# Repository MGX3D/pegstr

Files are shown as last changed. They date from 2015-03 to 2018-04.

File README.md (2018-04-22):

# Pegstr - Pegboard Wizard
__Parametric Peg Board Mounts Generator__
*Infinite ways to create pegboard holders and bins for tools or display objects.* 

__Highlights__:

* One or multiple (m•n matrix) objects per holder
* Round, square or rectangular with rounded corners
* Generate various shapes of bins and trays (closed bottom)
* Chose between stronger or economical, straight or tapered, etc
* Can be partially open (to click / snap in objects) and angled up or down

Note: This is designed to work with US-style pegboard (1/4" holes, 1" spaced) but I'm working on updating the design to support other pegboards requested in the comments.

Example objects:

Pegstr (https://youtu.be/gb9It1dF2z4)

Pegstr Bins (http://youtu.be/T17yfQddx3c)

Thingiverse page: http://www.thingiverse.com/thing:537516

Examples of mixed configurations:

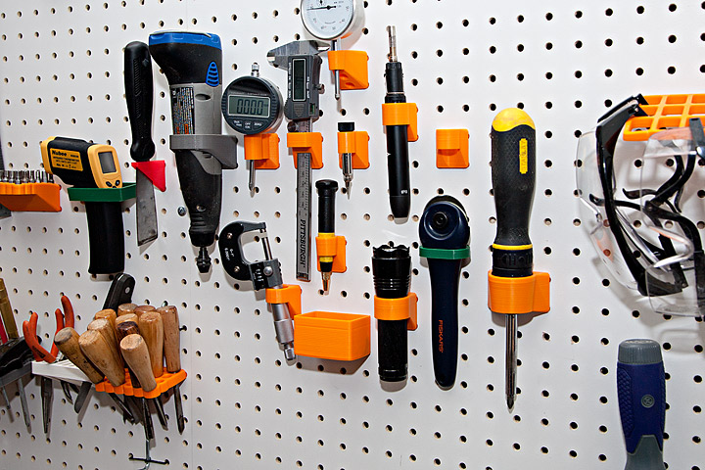
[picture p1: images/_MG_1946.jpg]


Example of MT2 supports:

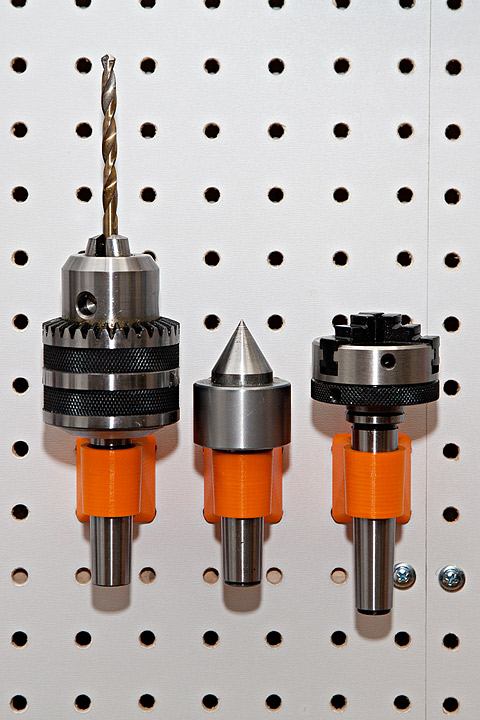
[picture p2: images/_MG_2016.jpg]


Example of hex bits holder:

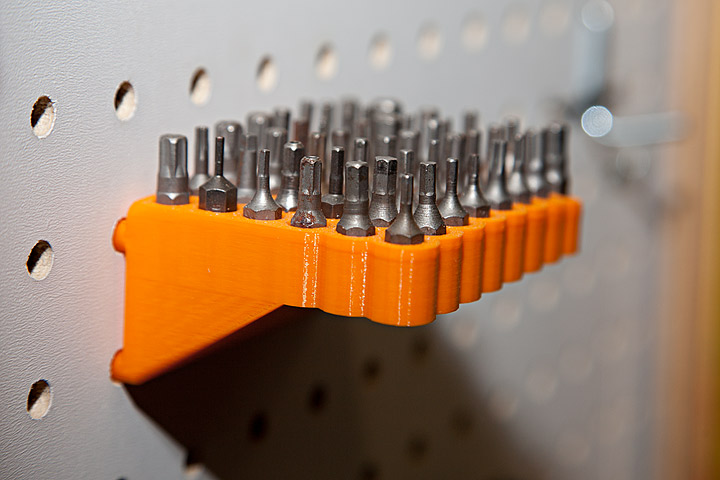
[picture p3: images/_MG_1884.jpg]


Note: this is CC-NC (Creative Commons - Attribution - Non-Commercial), if you intend to use this for commercial purposes please contact me first.

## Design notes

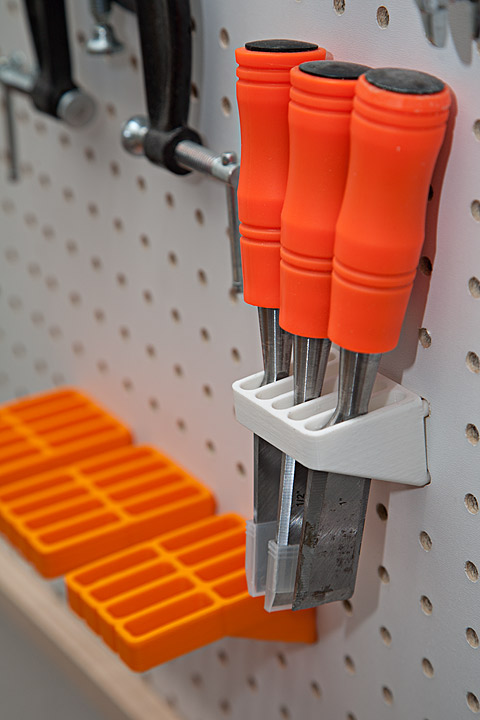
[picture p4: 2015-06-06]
images/_MG_1919.jpg

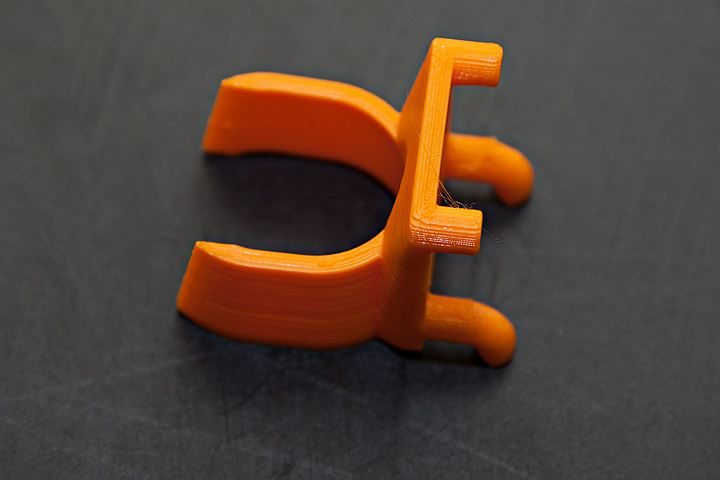
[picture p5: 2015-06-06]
images/_MG_2010.jpg

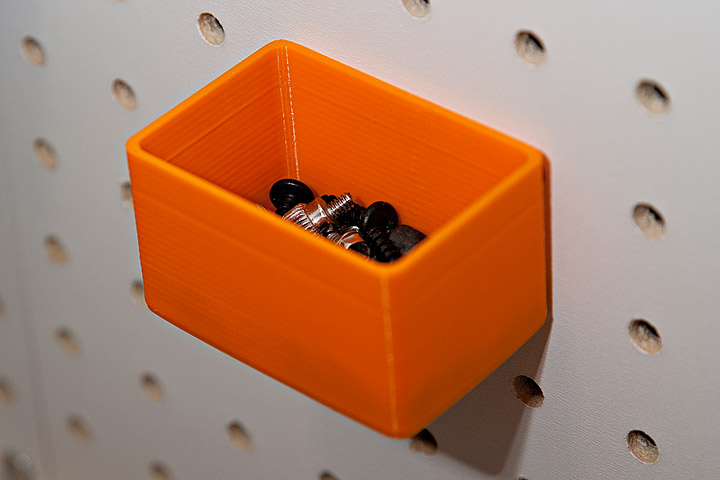
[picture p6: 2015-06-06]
images/_MG_1929.jpg

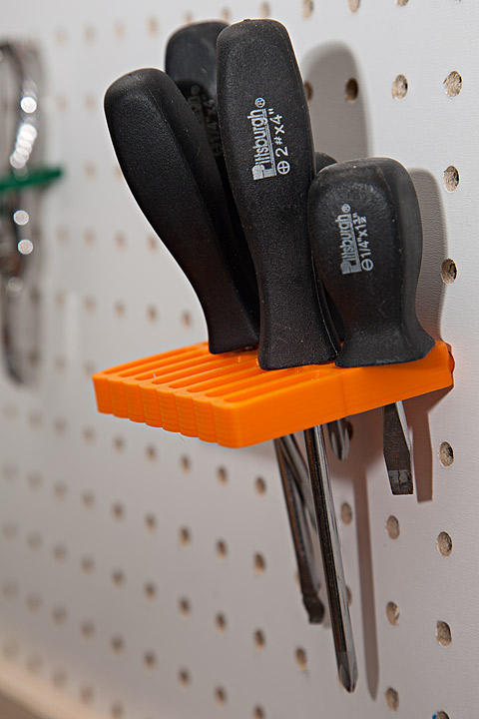
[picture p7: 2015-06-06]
images/_MG_1963.jpg

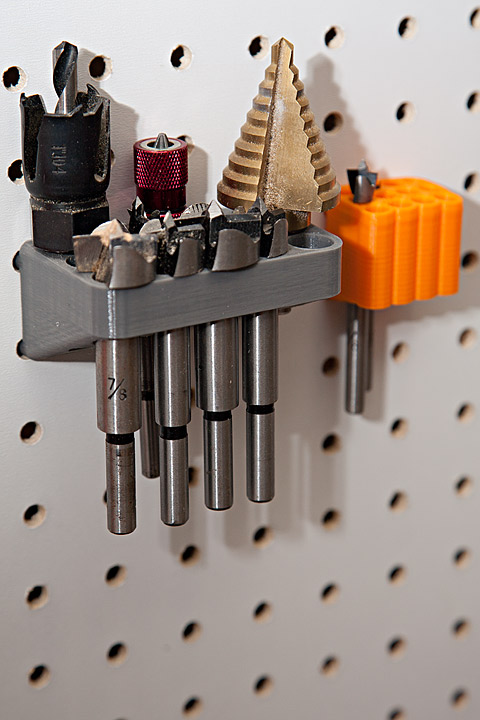
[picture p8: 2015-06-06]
images/_MG_1958.jpg

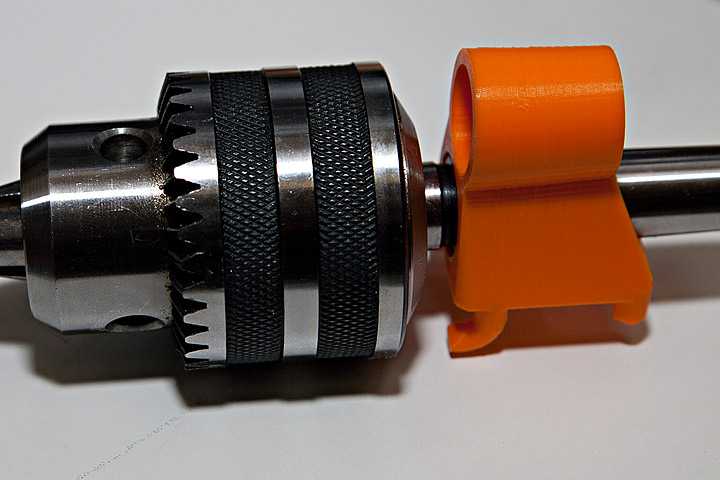
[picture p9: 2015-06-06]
images/_MG_1984.jpg

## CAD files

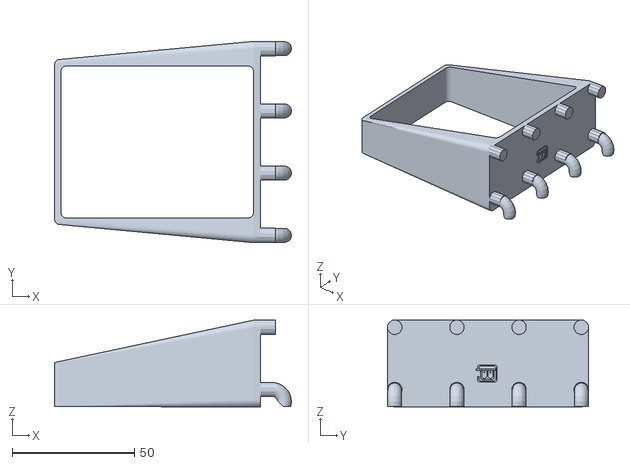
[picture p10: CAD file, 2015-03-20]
Samples/BD Matrix Drill Set/PegBoard_BDMatrix_base.stl
96.8 x 82.2 x 35.4

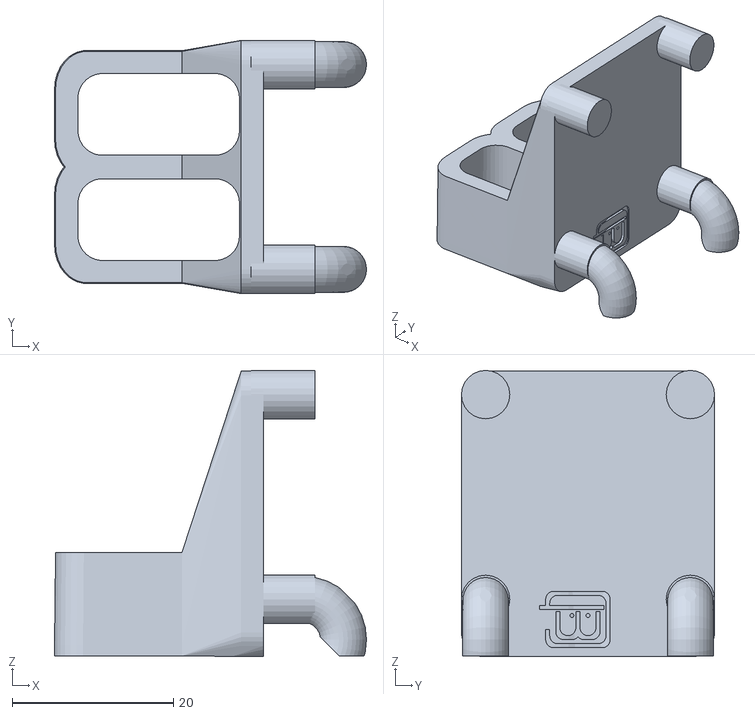
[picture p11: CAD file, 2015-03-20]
Samples/PegBoard_2by1_10x20.stl
38.7 x 31.4 x 35.5

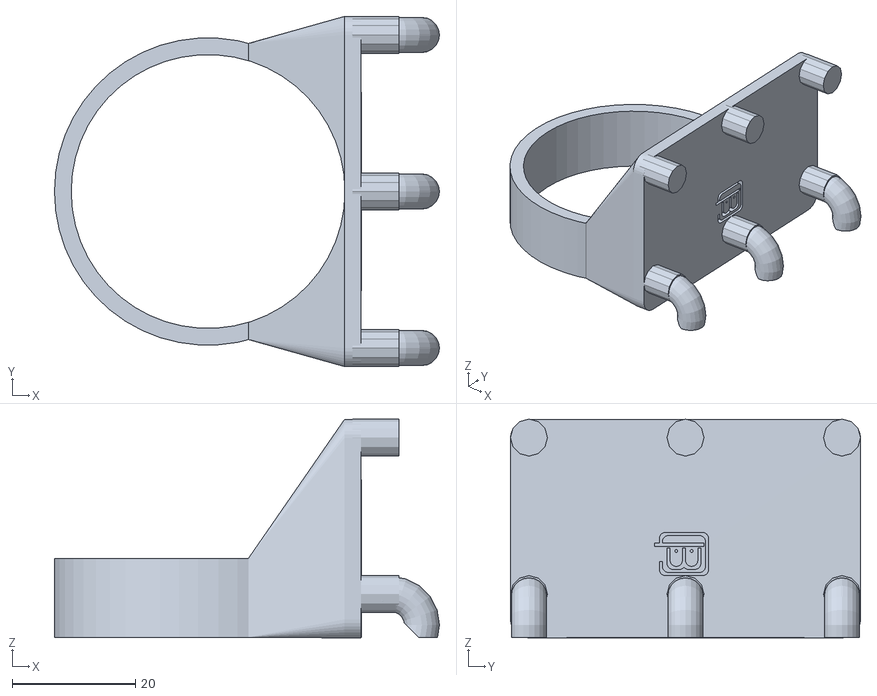
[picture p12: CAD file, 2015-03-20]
Samples/BD Matrix Drill Set/PegBoard_44mm.stl
62.5 x 56.8 x 35.5

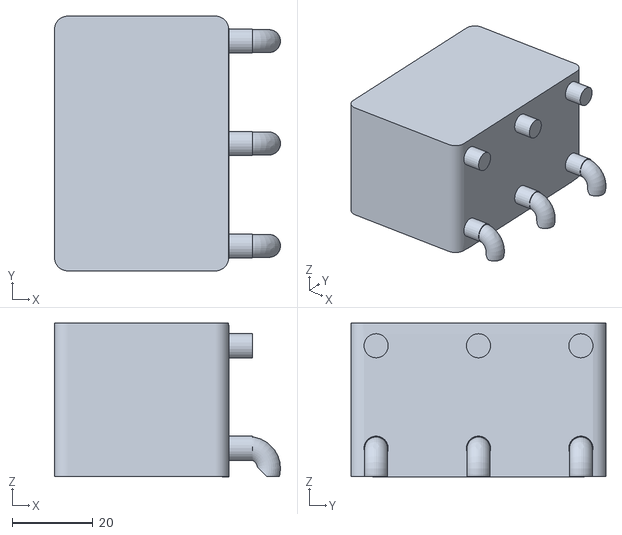
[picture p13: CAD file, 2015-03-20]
Samples/PegBoard_box_60x40.stl
56.1 x 63.2 x 38.1

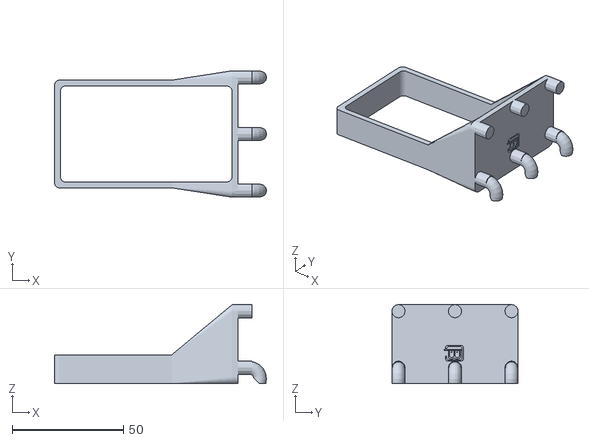
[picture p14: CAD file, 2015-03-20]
Samples/BD Matrix Drill Set/PegBoard_LBX20_battery.stl
95.3 x 56.8 x 35.5

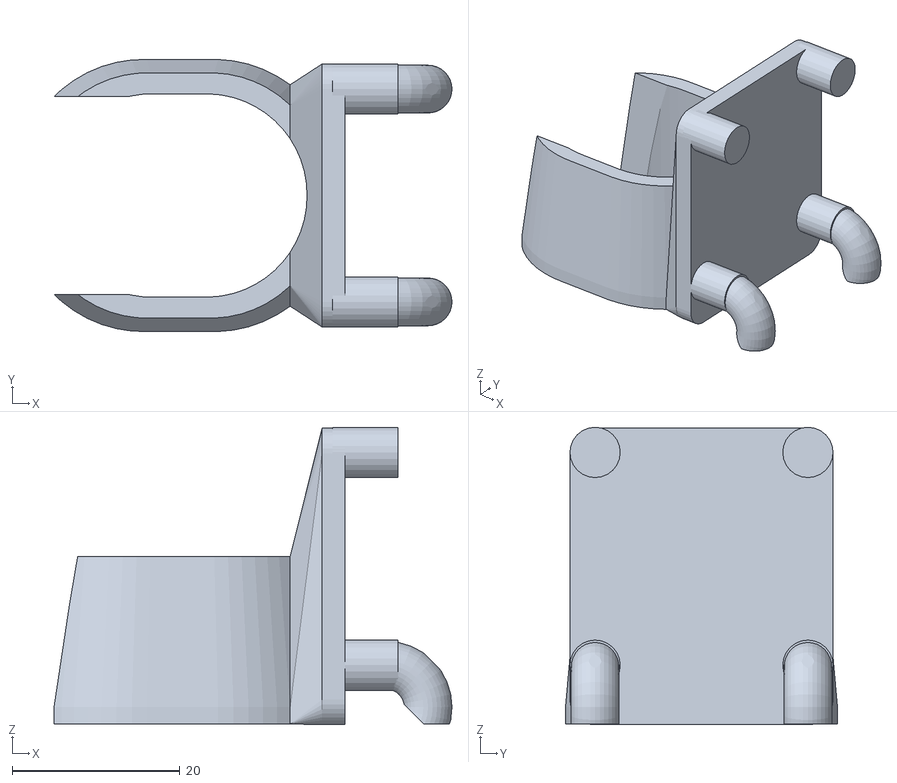
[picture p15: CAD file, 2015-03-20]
Samples/PegBoard_windscreen_tool.stl
47.5 x 32.5 x 35.5

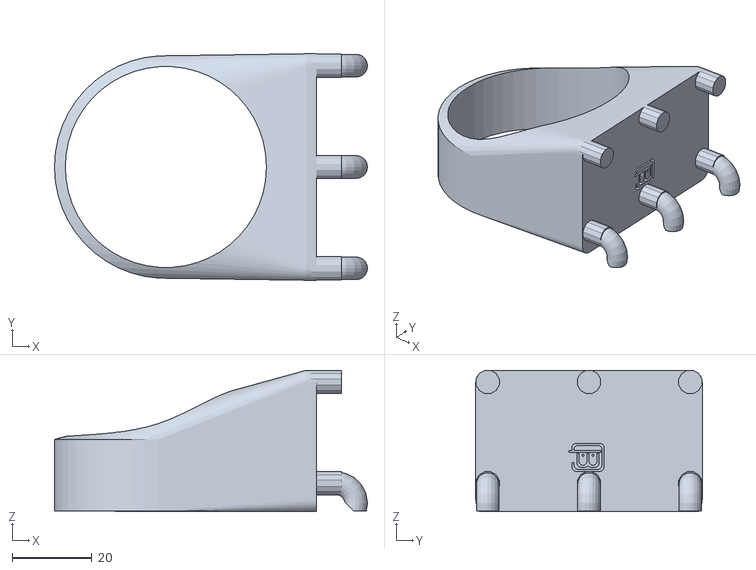
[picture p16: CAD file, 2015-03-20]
Samples/BD Matrix Drill Set/PegBoard_BDMatrix_tip.stl
78.5 x 56.8 x 35.4

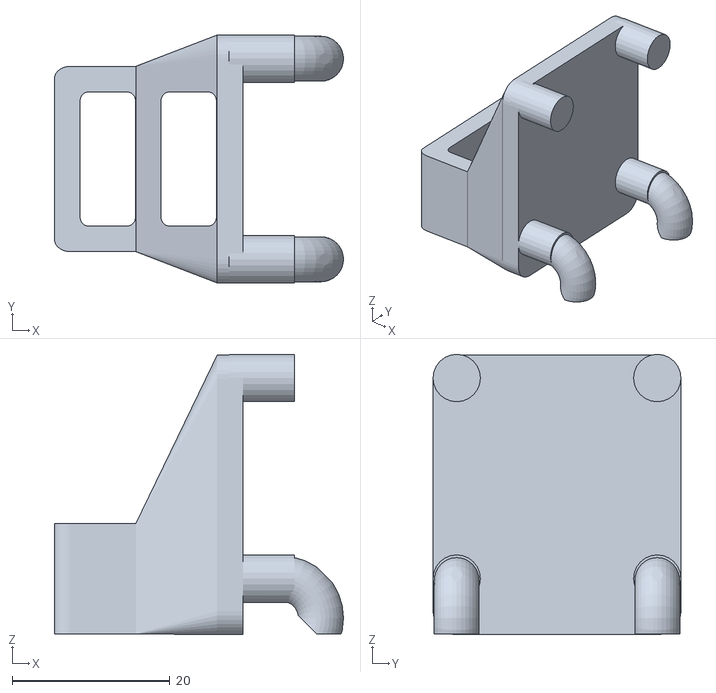
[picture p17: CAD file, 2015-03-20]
Samples/PegBoard_caliper.stl
36.6 x 31.4 x 35.5

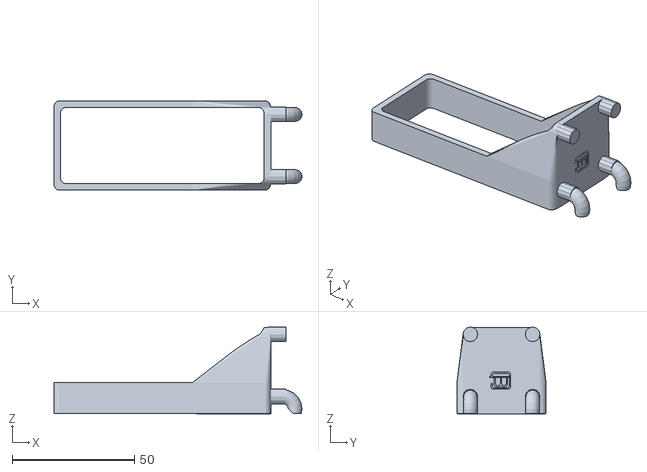
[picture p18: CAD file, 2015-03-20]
Samples/BD Matrix Drill Set/PegBoard_LBX20_charger.stl
101.3 x 36.4 x 35.5

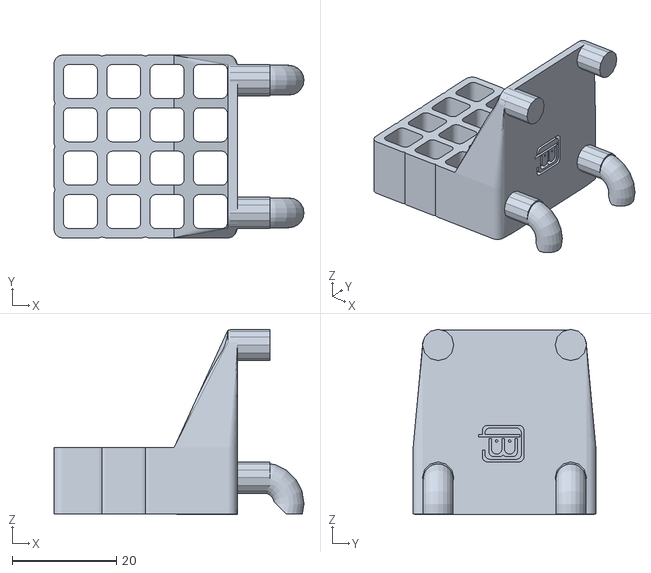
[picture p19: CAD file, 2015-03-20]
Samples/PegBoard_4by4_6.5x6.5.stl
47.9 x 35.0 x 35.5

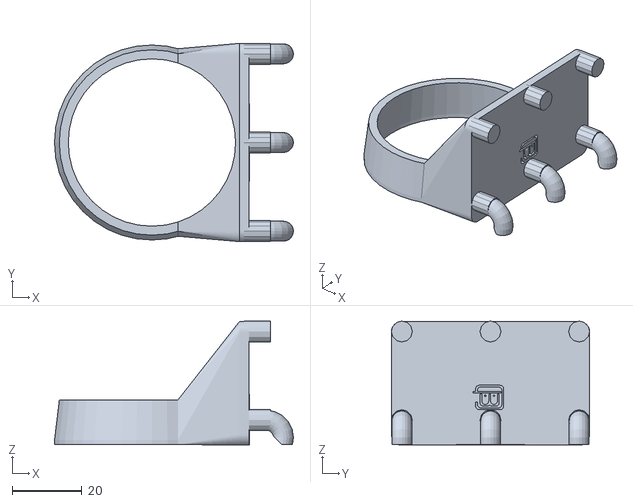
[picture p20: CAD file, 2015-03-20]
Samples/BD Matrix Drill Set/PegBoard_50mm_tapered.stl
68.5 x 56.8 x 35.5

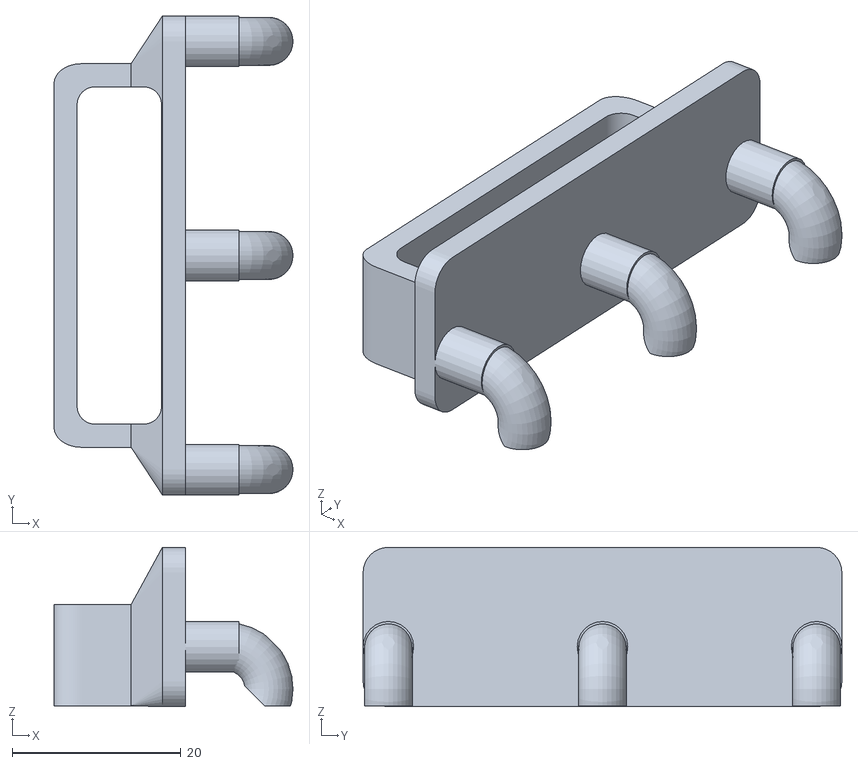
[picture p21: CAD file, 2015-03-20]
Samples/PegBoard_40x10_small.stl
28.4 x 56.8 x 18.9

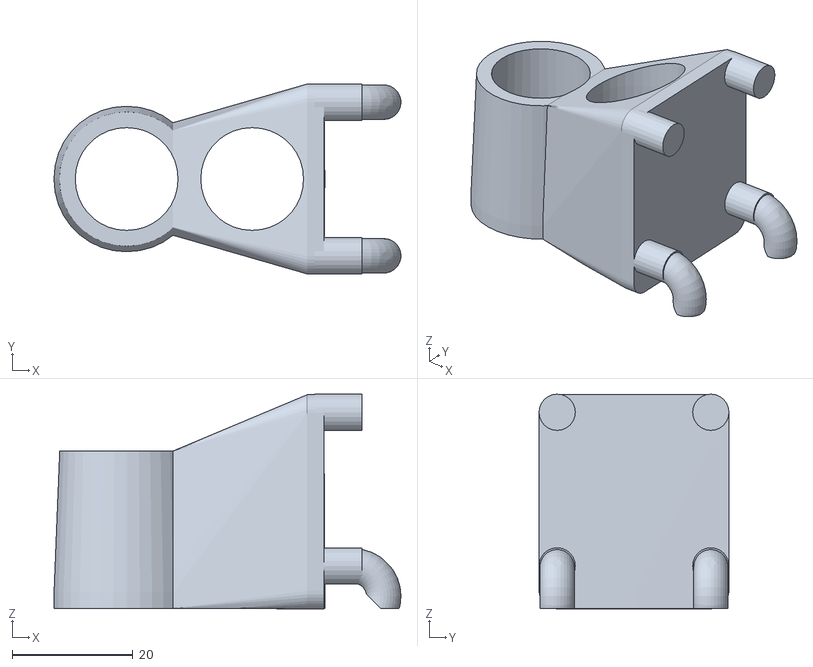
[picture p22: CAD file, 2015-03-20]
Samples/PegBoard_MT2.stl
57.4 x 31.4 x 35.5

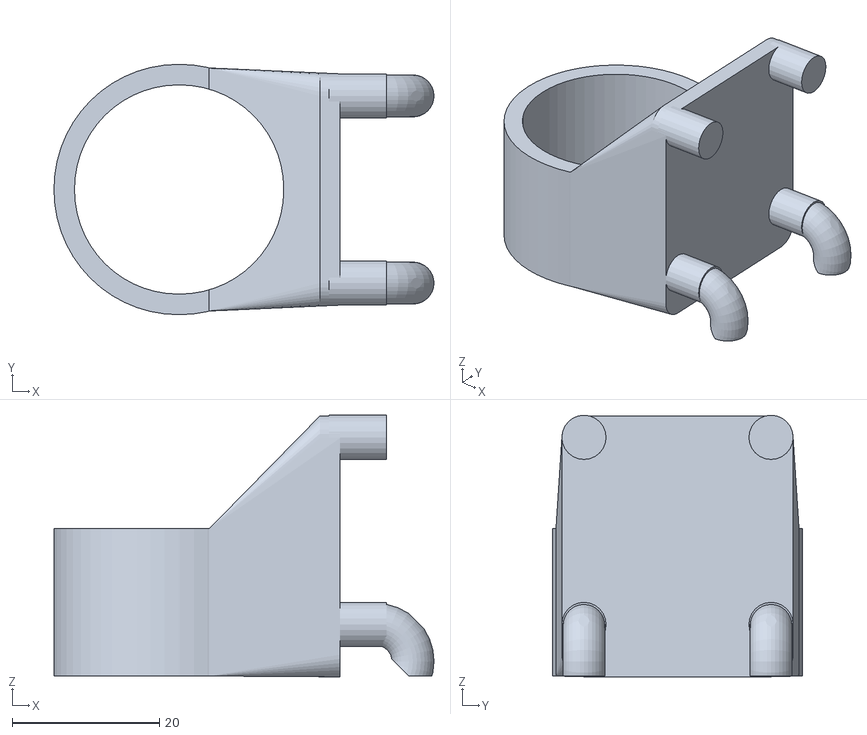
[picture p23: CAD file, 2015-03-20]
Samples/PegBoard_flashlight.stl
51.6 x 34.0 x 35.5

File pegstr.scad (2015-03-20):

// PEGSTR - Pegboard Wizard
// Design by Marius Gheorghescu, November 2014
// Update log:
// November 9th 2014
//		- first coomplete version. Angled holders are often odd/incorrect.
// November 15th 2014
//		- minor tweaks to increase rendering speed. added logo. 
// November 28th 2014
//		- bug fixes

// preview[view:north, tilt:bottom diagonal]

// width of the orifice
holder_x_size = 10;

// depth of the orifice
holder_y_size = 10;

// hight of the holder
holder_height = 15;

// how thick are the walls. Hint: 6*extrusion width produces the best results.
wall_thickness = 1.85;

// how many times to repeat the holder on X axis
holder_x_count = 1;

// how many times to repeat the holder on Y axis
holder_y_count = 2;

// orifice corner radius (roundness). Needs to be less than min(x,y)/2.
corner_radius = 30;

// Use values less than 1.0 to make the bottom of the holder narrow
taper_ratio = 1.0;


/* [Advanced] */

// offset from the peg board, typically 0 unless you have an object that needs clearance
holder_offset = 0.0;

// what ratio of the holders bottom is reinforced to the plate [0.0-1.0]
strength_factor = 0.66;

// for bins: what ratio of wall thickness to use for closing the bottom
closed_bottom = 0.0;

// what percentage cu cut in the front (example to slip in a cable or make the tool snap from the side)
holder_cutout_side = 0.0;

// set an angle for the holder to prevent object from sliding or to view it better from the top
holder_angle = 0.0;


/* [Hidden] */

// what is the $fn parameter
holder_sides = max(50, min(20, holder_x_size*2));

// dimensions the same outside US?
hole_spacing = 25.4;
hole_size = 6;//6.0035;
board_thickness = 5;


holder_total_x = wall_thickness + holder_x_count*(wall_thickness+holder_x_size);
holder_total_y = wall_thickness + holder_y_count*(wall_thickness+holder_y_size);
holder_total_z = round(holder_height/hole_spacing)*hole_spacing;
holder_roundness = min(corner_radius, holder_x_size/2, holder_y_size/2); 


// what is the $fn parameter for holders
fn = 32;

epsilon = 0.1;

clip_height = 2*hole_size + 2;
$fn = fn;

module round_rect_ex(x1, y1, x2, y2, z, r1, r2)
{
	$fn=holder_sides;
	brim = z/10;

	//rotate([0,0,(holder_sides==6)?30:((holder_sides==4)?45:0)])
	hull() {
        translate([-x1/2 + r1, y1/2 - r1, z/2-brim/2])
            cylinder(r=r1, h=brim,center=true);
        translate([x1/2 - r1, y1/2 - r1, z/2-brim/2])
            cylinder(r=r1, h=brim,center=true);
        translate([-x1/2 + r1, -y1/2 + r1, z/2-brim/2])
            cylinder(r=r1, h=brim,center=true);
        translate([x1/2 - r1, -y1/2 + r1, z/2-brim/2])
            cylinder(r=r1, h=brim,center=true);

        translate([-x2/2 + r2, y2/2 - r2, -z/2+brim/2])
            cylinder(r=r2, h=brim,center=true);
        translate([x2/2 - r2, y2/2 - r2, -z/2+brim/2])
            cylinder(r=r2, h=brim,center=true);
        translate([-x2/2 + r2, -y2/2 + r2, -z/2+brim/2])
            cylinder(r=r2, h=brim,center=true);
        translate([x2/2 - r2, -y2/2 + r2, -z/2+brim/2])
            cylinder(r=r2, h=brim,center=true);

    }
}

module old_pin(clip)
{
	rotate([0,0,15])
		cylinder(r=hole_size/2, h=board_thickness*1.5+epsilon, center=true, $fn=12);

	if (clip) {
		//
		rotate([0,0,90])
		intersection() {
			translate([0, 0, hole_size-epsilon])
				cube([hole_size+2*epsilon, clip_height, 2*hole_size], center=true);

			// [-hole_size/2 - 1.95,0, board_thickness/2]
			translate([0, hole_size/2 + 2, board_thickness/2]) 
				rotate([0, 90, 0])
				rotate_extrude(convexity = 5, $fn=20)
				translate([5, 0, 0])
				 circle(r = (hole_size*0.95)/2); 
			
			translate([0, hole_size/2 + 2 - 1.6, board_thickness/2]) 
				rotate([45,0,0])
				translate([0, -0, hole_size*0.6])
					cube([hole_size+2*epsilon, 3*hole_size, hole_size], center=true);
		}
	}
}

module pin(clip)
{
	rotate([0,0,15])
		#cylinder(r=hole_size/2, h=board_thickness*1.5+epsilon, center=true, $fn=12);

	if (clip) {
		//
		rotate([0,0,90])
		intersection() {
			translate([0, 0, hole_size-epsilon])
				cube([hole_size+2*epsilon, clip_height, 2*hole_size], center=true);

			// [-hole_size/2 - 1.95,0, board_thickness/2]
			translate([0, hole_size/2 + 2, board_thickness/2]) 
				rotate([0, 90, 0])
				rotate_extrude(convexity = 5, $fn=20)
				translate([5, 0, 0])
				 circle(r = (hole_size*0.95)/2); 
			
			translate([0, hole_size/2 + 2 - 1.6, board_thickness/2]) 
				rotate([45,0,0])
				translate([0, -0, hole_size*0.6])
					cube([hole_size+2*epsilon, 3*hole_size, hole_size], center=true);
		}
	}
}


module pinboard_clips() 
{
	rotate([0,90,0])
	for(i=[0:round(holder_total_x/hole_spacing)]) {
		for(j=[0:max(strength_factor, round(holder_height/hole_spacing))]) {

			translate([
				j*hole_spacing, 
				-hole_spacing*(round(holder_total_x/hole_spacing)/2) + i*hole_spacing, 
				0])
					pin(j==0);
		}
	}
}

module pinboard(clips)
{
	rotate([0,90,0])
	translate([-epsilon, 0, -wall_thickness - board_thickness/2 + epsilon])
	hull() {
		translate([-clip_height/2 + hole_size/2, 
			-hole_spacing*(round(holder_total_x/hole_spacing)/2),0])
			cylinder(r=hole_size/2, h=wall_thickness);

		translate([-clip_height/2 + hole_size/2, 
			hole_spacing*(round(holder_total_x/hole_spacing)/2),0])
			cylinder(r=hole_size/2,  h=wall_thickness);

		translate([max(strength_factor, round(holder_height/hole_spacing))*hole_spacing,
			-hole_spacing*(round(holder_total_x/hole_spacing)/2),0])
			cylinder(r=hole_size/2, h=wall_thickness);

		translate([max(strength_factor, round(holder_height/hole_spacing))*hole_spacing,
			hole_spacing*(round(holder_total_x/hole_spacing)/2),0])
			cylinder(r=hole_size/2,  h=wall_thickness);

	}
}

module holder(negative)
{
	for(x=[1:holder_x_count]){
		for(y=[1:holder_y_count]) 
/*		render(convexity=2)*/ {
			translate([
				-holder_total_y /*- (holder_y_size+wall_thickness)/2*/ + y*(holder_y_size+wall_thickness) + wall_thickness,

				-holder_total_x/2 + (holder_x_size+wall_thickness)/2 + (x-1)*(holder_x_size+wall_thickness) + wall_thickness/2,
				 0])			
	{
		rotate([0, holder_angle, 0])
		translate([
			-wall_thickness*abs(sin(holder_angle))-0*abs((holder_y_size/2)*sin(holder_angle))-holder_offset-(holder_y_size + 2*wall_thickness)/2 - board_thickness/2,
			0,
			-(holder_height/2)*sin(holder_angle) - holder_height/2 + clip_height/2
		])
		difference() {
			if (!negative)

				round_rect_ex(
					(holder_y_size + 2*wall_thickness), 
					holder_x_size + 2*wall_thickness, 
					(holder_y_size + 2*wall_thickness)*taper_ratio, 
					(holder_x_size + 2*wall_thickness)*taper_ratio, 
					holder_height, 
					holder_roundness + epsilon, 
					holder_roundness*taper_ratio + epsilon);

				translate([0,0,closed_bottom*wall_thickness])

				if (negative>1) {
					round_rect_ex(
						holder_y_size*taper_ratio, 
						holder_x_size*taper_ratio, 
						holder_y_size*taper_ratio, 
						holder_x_size*taper_ratio, 
						3*max(holder_height, hole_spacing),
						holder_roundness*taper_ratio + epsilon, 
						holder_roundness*taper_ratio + epsilon);
				} else {
					round_rect_ex(
						holder_y_size, 
						holder_x_size, 
						holder_y_size*taper_ratio, 
						holder_x_size*taper_ratio, 
						holder_height+2*epsilon,
						holder_roundness + epsilon, 
						holder_roundness*taper_ratio + epsilon);
				}

			if (!negative)
				if (holder_cutout_side > 0) {

				if (negative>1) {
					hull() {
						scale([1.0, holder_cutout_side, 1.0])
		 					round_rect_ex(
							holder_y_size*taper_ratio, 
							holder_x_size*taper_ratio, 
							holder_y_size*taper_ratio, 
							holder_x_size*taper_ratio, 
							3*max(holder_height, hole_spacing),
							holder_roundness*taper_ratio + epsilon, 
							holder_roundness*taper_ratio + epsilon);
		
						translate([0-(holder_y_size + 2*wall_thickness), 0,0])
						scale([1.0, holder_cutout_side, 1.0])
		 					round_rect_ex(
							holder_y_size*taper_ratio, 
							holder_x_size*taper_ratio, 
							holder_y_size*taper_ratio, 
							holder_x_size*taper_ratio, 
							3*max(holder_height, hole_spacing),
							holder_roundness*taper_ratio + epsilon, 
							holder_roundness*taper_ratio + epsilon);
					}
				} else {
					hull() {
						scale([1.0, holder_cutout_side, 1.0])
		 					round_rect_ex(
							holder_y_size, 
							holder_x_size, 
							holder_y_size*taper_ratio, 
							holder_x_size*taper_ratio, 
							holder_height+2*epsilon,
							holder_roundness + epsilon, 
							holder_roundness*taper_ratio + epsilon);
		
						translate([0-(holder_y_size + 2*wall_thickness), 0,0])
						scale([1.0, holder_cutout_side, 1.0])
		 					round_rect_ex(
							holder_y_size, 
							holder_x_size, 
							holder_y_size*taper_ratio, 
							holder_x_size*taper_ratio, 
							holder_height+2*epsilon,
							holder_roundness + epsilon, 
							holder_roundness*taper_ratio + epsilon);
						}
					}

				}
			}
		} // positioning
	} // for y
	} // for X
}


module pegstr() 
{
	difference() {
		union() {

			pinboard();
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

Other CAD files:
Samples/PegBoard_box_100x60.stl
Samples/PegBoard_2by2_10x10.stl
Samples/PegBoard_6by4_10mm.stl

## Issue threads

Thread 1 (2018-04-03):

Wall Control support?

rrauenza, 2018-04-03:
Hi!

This is more of an FYI -

I've forked your repo and am working on trying to get wall control hooks supported.  I have a metal peg board and it tears apart the 3d printed pegs.  But my board also supports Wall Control.   I was thinking of making supports that one could drop onto hooks like this:

https://www.wallcontrol.com/standard-slotted-hook-6-pack-7-8in-reach-black/

The board looks like this ..

https://www.wallcontrol.com/32in-x-16in-galvanized-metal-pegboard-tool-board-panel-metallic/

So the spacing is the same horizontally.

I'm pretty new at OpenSCAD so I'm struggling a bit, so if this is something you'd (or anyone else) be interested in helping support, please let me know.

rrauenza, 2018-04-11:
It mostly works ... I'm just not satisfied with how hard it is to move the items once inserted (and its an excuse to learn some CAD).

The 3d printed pegs just aren't super strong -- the ones that break tend to be at the sides, I think because there is less support material?  Or maybe that's where I put pressure on them to remove.

It might be tolerances in my printer, but I also want to make sure the items are secure and don't constantly fall out (like all the metal ones do!), so I don't want to just shrink the pegs

I got frustrated with OpenSCAD's requirement of having epsilon's everywhere for cuts, so jumped into Fusion360.  I've posted some designs on thingiverse -- one of the STLs contains the hook / hanger module.

https://www.thingiverse.com/thing:2852340

Feel free to close...

Closed 2018-04-22.

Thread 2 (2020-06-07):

4 mm hole size

Thoky81, 2020-06-07:
Hi,
I would like to ask you how can I change the pins to fit EU pegboard hole size which is approx. 3.5-4.0 mm in diameter.
When I open the scad file in OpenScad I found these settings:

```
// dimensions the same outside US?
hole_spacing = 25.4;
hole_size = 6.0035;
board_thickness = 5;
```

But when I change the hole_size to let say 3.5 the corner of the pins are strange and not in line. See the picture:

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

Thank a lot

martinvw, 2020-06-07:
I created a fork for my pegboard I don’t know whether you have the same board but you could check out my fork:  https://www.thingiverse.com/thing:4333614

The first image shows the holes of my board, if it helps your feedback is appreciated!

Thoky81, 2020-06-07:
Thanks for reply. I have checked your fork but its not working for my. My one its not metal and I have just round holes. Do you have any idea how to solve it?

raulvera59, 2020-06-18:
I had the same problem, so I fixed the pin function. I don't feel up to doing a full pull request, but if you replace the pin module, from line 109 to line 134, with the following, the clips are a bit different and the pins and clips scale properly with the hole size and board thickness.

```
clip_radius = 5;
pin_length = board_thickness;

module pin(clip)
{
    rotate([0,0,15])
    cylinder(r=hole_size/2, h=board_thickness*1.5+epsilon, center=true, $fn=12);

    if (clip) {
        rotate([0,0,-90])
        translate([0,-clip_radius, pin_length/2])
        intersection() {
            rotate([0,90,0])
            rotate_extrude(convexity = 5, $fn =20)
            translate([clip_radius,0,0])
            circle(r = (hole_size*0.95)/2);

            translate([-hole_size/2, 0, 0])
            cube([hole_size+2*epsilon, clip_radius+hole_size, clip_radius+hole_size], center = false);
        }
    }
}
```

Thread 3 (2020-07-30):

First layer incomplete when printing upside down

jeffminton, 2020-07-30:
when slicing upside down (with the tops of the hooks facing down) it appears that some of the model is not flush with the build plate. I have noticed when looking at the tool path that the front of the holes and the first layer of the hooks are not being printed.

I have uploaded two screenshots from cura. The first shows the model in the orientation I am slicing it. The second shows the path of the first layer of the print where the parts I mention are seen to be missing.

I am using cura 4.6.1.

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

MGX3D, 2020-08-20:
Can you share the parameters used? Note not all variants can be printed without supports, especially the ones that are angled (it's not possible to have both the pins and the top of the object in the same plane).

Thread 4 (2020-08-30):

Support for European pegboard

MGX3D, 2020-08-30:
30mm spacing, 8mm round holes
15mm spacing, 4mm round holes
38mm spacing, 9mm square holes (Finland)

sir106, 2020-12-06:
would also love to have the "15mm spacing, 4mm round holes" solution available...

rockas69, 2021-08-14:
is there any way to select spacing and round holes sizes? If so, how can I do it?

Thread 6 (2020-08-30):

Support for South Africa pegboard

MGX3D, 2020-08-30:
Metric system: 3mm Thick, 4mm Hole Size, 25mm Hole Spacing.
https://en.wikipedia.org/wiki/Perforated_hardboard

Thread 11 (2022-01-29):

How to support through donation?

f1yn, 2022-01-29:
I'm a single parent, and this parametric design has allowed me to:

- See a real (useful) example of parametric design
- Have a real-world example of where OpenSCAD can wipe the floor with normal cad design
- Saved me money (instead of having to buy overpriced prefabs online), which I can spend on my daughters and other things.

I've been smashing through self-learning materials for CAD design, and honestly this is the only useful paramateric design I've seen so far - so thank you.

I'd like to send a donation as a thank-you for this, but the only option I can find is on Thingiverse (which, I'd like to avoid donating to). Can you update the readme with some option for donating, or even consider support through GitHub?

- Thanks

f1yn, 2022-05-17:
Felt like I should leave an update.

I did what felt like bounty hunting for a while (looking for an email, or some online account that wasn't deal), but I eventually tracked down Marius on Printables: https://www.printables.com/social/48368-mgx/about

I tried reaching out, but I think I spooked him. He did add a PayPal link to his account though so I ending up making a donation through there. You can find the *Donate* link on the Printables profile.

Maybe he'll come back, maybe not - but for those who are interested this model is also here: https://www.printables.com/model/34992-pegstr-pegboard-wizard

Closed 2022-05-17.

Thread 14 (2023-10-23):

Support for Honeycomb Storage Wall

blitzaxt, 2023-10-23:
I have started using the Honeycomb Storage Wall which  is a really cool project that replaces a pegboard with a printed hexagon board.

I have often used the Pegstr project to create useful holders for my pegboards and I'm doing my best to add support for the Honeycomb Storage Wall(HSW). I've created a fork but I am no expert when it comes to OpenSCAD and I'm not sure how to best integrate the changes with the current project. It currently produces a seemingly functional holder (need to actually print one but the principles are there) and I will continue working on it when I have a minute. I will be printing a few holders for testing.

Link to HSW: https://www.printables.com/model/152592-honeycomb-storage-wall/files (Printables, didn't find a readily available git repo)
Link to my Fork: https://github.com/blitzaxt/pegstr-honeycomb-storage-wall

I have not contributed to a ton of projects so let me know if I'm missing anything or I can do something better :smile:.
Thanks so much for this project!

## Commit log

2015-03-20 Initial set of samples
    [PegBoard_2by1_10x20.stl, PegBoard_2by2_10x10.stl, PegBoard_40x10_small.stl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]
2015-03-20 Sample: Black&Decker Matrix Drill Set
    [PegBoard_44mm.stl, PegBoard_50mm_tapered.stl, PegBoard_BDMatrix_base.stl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]
